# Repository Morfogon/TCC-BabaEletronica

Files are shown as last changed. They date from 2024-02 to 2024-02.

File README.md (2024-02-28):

# Baba Eletrônica Para Pais Deficientes Auditivos ( BabyCare )
Trabalho de conclusão de curso de Engenharia da Computação, Instituto Mauá de Tecnologia



O projeto consiste em:
- [x] Criação de modelos de aprendizagem para classificação e detecção de choro @NULLBYTE-RGH
- [x] Fazer captura de Som e Imagem do bebê com uma Webcam (Streaming) @NULLBYTE-RGH
- [x] Criar um Barramento de eventos para gerenciar a comunicação entre o serviço de classificação e periféricos @NULLBYTE-RGH
- [x] Criar meios de Autenticação e implementar criptografia @NULLBYTE-RGH
- [x] Fazer comunicação entre bracele e Baba eletrônica @NULLBYTE-RGH
- [x] Criar metodo de configuração da Baba a rede WIFI via bluetooth @NULLBYTE-RGH
- [x] Criação e implementação de um bracelete de uso do bebê para captura de movimentos e comunicação com a central (Intel NUC) @NULLBYTE-RGH
- [x] Criação e implementação de Modulo de controle de iluminação @NULLBYTE-RGH
- [x] Implementar serviços de forma eficiente, visando baixo uso de recursos @NULLBYTE-RGH
- [x] Criação e integração de um relógio inteligente que ligado ao celular via bluetooth recebe notificações e alerta os pais por meio de vibração e ou alerta visual @NULLBYTE-RGH
- [x] Criação de modelos de braceletes para impressao 3D para o pai e para o bebe @NULLBYTE-RGH
- [x] Criação de APP para comunicação com a baba eletrônica, possibilitando a visualização do bebê em tempo real bem como acesso a logs de choro @NULLBYTE-RGH @Morfogon

Status do projeto:



-----------------------------------------------------------------------------------------------------------------------------------------------

ConjuntoBABA

-----------------------------------------------------------------------------------------------------------------------------------------------

## ✔️ Técnicas, tecnologias e Recursos utilizados

- ``Python 3.10``
- ``Thony 3.3.13``
- ``Flask 2.2.3``
- ``Requests 2.28.2``
- ``Socket``
- ``Json``
- ``Numpy 1.23.5``
- ``Pyaudio 0.2.13``
- ``Time``
- ``Librosa 0.10.0.post2``
- ``Sklearn``
- ``Pickle``
- ``Datetime``
- ``Cv2 4.7.0.72``
- ``PIL``
- ``Io``
- ``Threading``
- ``Serial``
- ``RPi``
- ``Tensorflow 2.8.0``
- ``Soundfile 0.12.1``
- ``Machine``
- ``Imu``
- ``Math``
- ``matplotlib 3.7.1``
- ``os``
- ``Pydub 0.25.1``
- ``Scipy 1.10.1``
- ``Noisereduce``
- ``Comunicação UART``
- ``Comunicação I2C``
- ``Postman 10.13.0``
- ``Openssl``
- ``PyCharm Professional 231.8770.66, built on April 27, 2023`` ❤️
- ``DataSpell 231.8770.72, built on May 3, 2023`` ❤️

## 💻 Hardware para Treinamento e Desenvolvimento

- ``NVIDIA GeForce RTX 2060``
- ``Intel Core i7-8750H 2.20 GHz``
- ``16 GB RAM``

## Central da Baba
- ``Intel nuc dn2820fykh``
  
-----------------------------------------------------------------------------------------------------------------------------------------------
## Diagrama do projeto

Baba eletronicav3 drawio

VISAO COMPLETA BABA

## Modelos Testados:
#### Modelos clássicos, apresentaram uma boa precisão porém para a quantidade de dados disponíveis nos Datasets não foram eficientes
### SVC: 
SVC
### RandomForest:
Random
### DecisionTree:
Decision

-----------------------------------------------------------------------------------------------------------------------------------------------

#### Classificador MLP
#### 100 Neurônios para classificação de Choro, Silencio, Barulho e Risadas:
100Camadas
#### 600 Neurônios para classificação de Cólica, Arroto, Desconforto, Fome e cansaço:
600Camadas
#### 100 Neurônios com audios passados pelo microfone (Modelo mais recente):
output
#### A precisão máxima é atingida em vários momentos com diferentes features e com testes foi verificado que apesar de com 1 feature a precisão ser de 84%, com o uso de 26 Features, que também resulta em uma precisão de 84%, o modelo se sai melhor.
##### A classe CryingV2 utilizada no Neural.ipynb nada mais é do que uma pasta contendo ['belly_pain','discomfort','hungry','tired', 'Crying']
##### E o aprendizado foi feito em um ambiente utilizando Python versão 3.10
#### Sendo assim os modelos que serão utilizados em testes sem ruídos e estao disponiveis na pasta /Modelos são:
#### [x] modelo_Apenas_ChoroV4.pkl -> 95%
#### [x] modelo_Tipos_De_ChoroV4.pkl -> 84%
#### [x] Novo_Modelo_MLP_NormalizadoV3.pkl ->94.64%
##### É possível que o MLP tenha obtido melhores resultados porque ele é capaz de extrair mais informações relevantes dos dados de áudio e generalizar melhor para novos dados. Como mencionado anteriormente, os outros modelos podem ter limitações em termos de capacidade de lidar com dados mais complexos e não lineares.

##### Além disso, o fato de que o MLP teve um desempenho melhor no teste real pode ser uma indicação de que ele não sofreu tanto de overfitting quanto os outros modelos. O overfitting ocorre quando o modelo é ajustado demais aos dados de treinamento e não generaliza bem para novos dados. Se o MLP generalizou melhor para novos dados, é possível que ele tenha sofrido menos de overfitting do que os outros modelos.

-----------------------------------------------------------------------------------------------------------------------------------------------
 
### Problemas na captura de Áudio via Microfone:
#### Ao capturar o mesmo áudio que foi utilizado no treinamento via microfone foi observado uma diferença gritante:
### Espectrograma:
#### Louise é o audio original do dataset:
Espectrograma-Louise
#### Som do Bebe é o audio da Louise do dataset regravado a partir do microfone do computador:
Espectrograma Captura_WebCam

### Gráfico de Frequência:
#### Louise é o audio original do dataset:
Frequencia_Louise
#### Som do Bebe é o audio da Louise do dataset regravado a partir do microfone do computador:
Frequencia_WebCam

#### Foi testado o Treinamento do MLP com áudios gravados pelo Microfone, ao invés do uso do Dataset original, esses áudios do microfone nada mais são do que os áudios do dataset original, porém passados pelo Microfone que será usado para captura do áudio do Bebê, assim eliminando a interferência do Transdutor no reconhecimento.
#### Foi testado com 5 áudios de cada categoria e foi verificado que se obteve uma precisão de acerto de 4 em 5 dessa forma. Isso com 26 MFCCs e 100 Neurônios na camada. E apenas 20 dados para aprendizado sendo que dos 20, 20 % foram utilizados na validação resultando em 75 % de precisão. 
(Modelo: modelo_Tipos_De_ChoroVMicrofone.pkl)

### Áudios comparados (Original) e mesmo áudio, porém com influência do transdutor e com menor amplitude de dB:

#### Espectrogramas dessa vez com taxa de amostragem correta (Pois nos datasets baixados existem vários áudios fora do padrão 22k, isso foi corrigido junto ao tempo de áudio variado, agora limitados a 5 segundo e salvos em pastas com V2 no final do nome, dentro da pasta datasets) e com o microfone de um Galaxy s20+ ao invés do microfone da webcam:

Espectrograma Audio Original

Espectrograma Audio passado pelo Microfone

### Influência do dB na normalização do MFCC (Muito baixa a quase nula) assim comprovando que o volume não influencia na extração de fatures para criação do modelo/classificação:
##### Por camadas internas, entenda Neuronios, pois foi feito com apenas 1 camada, tirando a SoftMax
MFCC1

MFCC2

MFCC3

MFCC4

#### Novos datasets foram criados a partir dos datasets existentes, porém os áudios foram tocados em caixas de som que foram capturadas por uma webcam com microfone integrado, esses áudios então foram segmentados e salvos em suas respectivas classes, que foram utilizadas para treinamento do novo modelo e mais preciso de todos até o momento, com 95.38% de precisão, o modelo (modelo_Tipos_De_ChoroVMicrofone.pkl) faz uso de 90 mfcc's, 300 neurônios e 30% do dataset para validação. (dataset utilizado foi o Dataset_Microfone, onde todos os áudios limpos, em questão de samples e duração, foram tocados por uma caixa de som e capturados pelo microfone da webcam)

### O modelo mais recente:

#### O modelo atual 
[Novo_Modelo_MLP_NormalizadoV3.pkl](https://github.com/NULLBYTE-RGH/Baba-Eletronica-Para-Pais-Deficientes-Auditivos/blob/main/Modelos/Novo_Modelo_MLP_NormalizadoV3.pkl) junto ao 
[Scaler](https://github.com/NULLBYTE-RGH/Baba-Eletronica-Para-Pais-Deficientes-Auditivos/blob/main/Modelos/scalers_Novo_Modelo_MLP_NormalizadoV3.pkl)
faz uso de 1 camada interna com apenas 40 Neurônios e tem como entrada da rede 100 mfccs sendo o modelo mais leve e menos complexo ate o momento, atingindo uma precisao de 94.64%. Ele foi treinado com um novo dataset, que na verdade sao usados os mesmo audios que tinham no V2, porem eles foram tocados atraves de uma caixa de som nova e mais robusta, e alem disso foi feita uma limpeza manual em cada audio, removendo audios ruins ou inconsistentes com a classe. Junto a isso com a uma limpeza adicional nos audios, resultou em uma diminuição do Dataset, resultando em 76 audios de choro, 38 de risada e 72 de barulhos externos, visto um certo desbalanceamento foi tantado fazer ajustes ao modelo aplicando diferentes pesos as clases e fazendo dados sinteticos, e  resultado final foi :

Metricas Classificador

#### As especificações da nova caixa de som é : modelo: ep310, rms: 5w, resposta a frequencia: 200hz - 18 khz, sensibilidade de entrada: 350 mv, voltagem: 5v dc, conexão: p2

#### Os audios foram reproduzidos com o som maximo da caixa de som, porem com o nivel 80 % do windows, e a distancia entre a webcan e a caixa de som é de cerca de 1 metro
-----------------------------------------------------------------------------------------------------------------------------------------------

## Bracelete do Bebê
#### Componentes:
##### [X] RP2040
##### [X] HC05
##### [X] GY-521

Schematic_Braceletes_2023-05-07

[Schematic_Braceletes_2023-05-07.pdf](https://github.com/NULLBYTE-RGH/Baba-Eletronica-Para-Pais-Deficientes-Auditivos/files/11414012/Schematic_Braceletes_2023-05-07.pdf)





-----------------------------------------------------------------------------------------------------------------------------------------------

## Bracelete dos Pais
#### Componentes:
##### [X] RP2040
##### [X] HC05
##### [X] Motor Vibrador 3v

Schematic_Bracelete PAI_2023-05-12

-----------------------------------------------------------------------------------------------------------------------------------------------
## Modulo de Iluminação

Schematic_Luz_2023-09-06

-----------------------------------------------------------------------------------------------------------------------------------------------

## 🔨 Funcionalidades: [Barramento de eventos](https://github.com/NULLBYTE-RGH/Baba-Eletronica-Para-Pais-Deficientes-Auditivos/tree/main/Barramento%20de%20eventos)
#### Ao [iniciar](https://github.com/NULLBYTE-RGH/Baba-Eletronica-Para-Pais-Deficientes-Auditivos/blob/main/Fluxograma/Inicializa%C3%A7%C3%A3o.pdf) o dispositivo o [serviço de inicialização](https://github.com/NULLBYTE-RGH/Baba-Eletronica-Para-Pais-Deficientes-Auditivos/blob/main/Barramento%20de%20eventos/servi%C3%A7os/Servico_de_Inicializacao.py) entra em execução, se for a primeira inicialização, o usuario deverá, parear seu celular com a Raspberry pi 3 e segurar o botão nela contido por X segundos, sendo assim o serviço: [Serviço_de_conexao_wifi](https://github.com/NULLBYTE-RGH/Baba-Eletronica-Para-Pais-Deficientes-Auditivos/blob/main/Barramento%20de%20eventos/servi%C3%A7os/Servico_Rede_WIFI.py) entrara em funcionamento, a partir desse momento o usuário por meio do app deverá informar o SSID(nome) da rede [wifi](https://github.com/NULLBYTE-RGH/Baba-Eletronica-Para-Pais-Deficientes-Auditivos/blob/main/Fluxograma/Rede%20WIFI.pdf) e sua senha, quando conectado corretamente, é retornado o IP da Baba eletronica na rede local e é solicitado a criação de pelo menos um usuario e uma senha, tendo a opção da criação de multiplas contas. Ao finalizar, o serviço [Barramento](https://github.com/NULLBYTE-RGH/Baba-Eletronica-Para-Pais-Deficientes-Auditivos/blob/main/Barramento%20de%20eventos/Barramento.py) entrara em execução, juntamente aos serviços : [Bracelete](https://github.com/NULLBYTE-RGH/Baba-Eletronica-Para-Pais-Deficientes-Auditivos/blob/main/Barramento%20de%20eventos/Bracelete.py), [Camera](https://github.com/NULLBYTE-RGH/Baba-Eletronica-Para-Pais-Deficientes-Auditivos/blob/main/Barramento%20de%20eventos/Camera.py), [Microfone](https://github.com/NULLBYTE-RGH/Baba-Eletronica-Para-Pais-Deficientes-Auditivos/blob/main/Barramento%20de%20eventos/Microfone.py) e [iluminacao](https://github.com/NULLBYTE-RGH/Baba-Eletronica-Para-Pais-Deficientes-Auditivos/blob/main/Barramento%20de%20eventos/iluminacao.py)
##### Exemplo de saida quando a Baba esta sendo configurada pelo [Serviço_de_conexao_wifi](https://github.com/NULLBYTE-RGH/Baba-Eletronica-Para-Pais-Deficientes-Auditivos/blob/main/Barramento%20de%20eventos/servi%C3%A7os/Servi%C3%A7o_de_conexao_wifi.py), essa saida foi gerada com uso do app [Serial Bluetooth Terminal](https://play.google.com/store/apps/details?id=de.kai_morich.serial_bluetooth_terminal&pli=1) para Android, fazendo as requisições que serao feitas pelo APP:
Screenshot_20230508_000623_Serial Bluetooth Terminal
-----------------------------------------------------------------------------------------------------------------------------------------------
## [Rotas](https://github.com/NULLBYTE-RGH/Baba-Eletronica-Para-Pais-Deficientes-Auditivos/blob/main/Fluxograma/Barramento.pdf)

##### O Barramento em si [Barramento.py](https://github.com/NULLBYTE-RGH/Baba-Eletronica-Para-Pais-Deficientes-Auditivos/blob/main/Barramento%20de%20eventos/Barramento.py) tem diversas rotas e roda na porta padrão 5000 (Atualmente tudo funciona por meio de HTTP, futuramente sera implementado HTTPS, para uma maior segurança da baba como um todo):
###### Para todas as requisições (Exceto /camera), deve ser fornecido tanto o usuario como a senha : (usuario&senha) em formato JSON no corpo da requisição como : 
##### {
##### "usuario":"user1",
##### "senha":"pass1"
##### }
##### ``Caso tenha um metodo associado a rota (?tipo=X)``
##### Para criar o certificado e par de chaves para usar HTTPS TLS use o OpenSSL: 
##### ``openssl req -x509 -newkey rsa:4096 -nodes -out cert.pem -keyout key.pem -days 365`` 
##### Este comando criará um certificado autoassinado com uma chave RSA de 4096 bits e uma validade de 365 dias
###### As requisições podem ser consultadas [aqui](https://github.com/NULLBYTE-RGH/Baba-Eletronica-Para-Pais-Deficientes-Auditivos/blob/main/Requisi%C3%A7%C3%B5es/Barramento.postman_collection.json)
-----------------------------------------------------------------------------------------------------------------------------------------------
### '[/](https://github.com/NULLBYTE-RGH/Baba-Eletronica-Para-Pais-Deficientes-Auditivos/blob/main/Fluxograma/Barramento.pdf)'
###### Deve ser acessada via método POST, essa rota serve para escrever o celular como Observer dos eventos do bebê, para evitar excessivo tráfego na rede. Ao momento que o celular sabe o endereço da baba na rede, ele envia essa requisição ao celular e o barramento se encarrega de avisar o celular caso tenha ocorrido alguma mudança na movimentação do bebê ou caso tenha ocorrido choro. assim o [celular](https://github.com/NULLBYTE-RGH/Baba-Eletronica-Para-Pais-Deficientes-Auditivos/blob/main/Barramento%20de%20eventos/Simular_Celular.py) como simulado, pode tomar a decisão de alertar o usuário. Mais detalhadamente, essa rota ao receber a requisição extrai o IP do celular na rede, bem como a porta em que o celular escolheu para ouvir notificações, essa porta é enviada pelo celular no corpo da requisição, essa porta é de escolha do celular, podendo ser modificada caso necessário, em tempo de Execução.


-----------------------------------------------------------------------------------------------------------------------------------------------
### '/evento'
###### É uma rota de método POST na qual ``o usuário não deve acessar`` (para isso é feita uma checagem de IP na hora que o barramento recebe a requisição, assegurando que o IP do cliente é da rede de loopback, assim só permitindo que serviços locais, iniciem requisiçoes a essa rota), essa rota é de acesso dos serviços em execução, ao ocorrer alguma mudança de estado dos servicos execução,o serviço alerta o barramento por meio desta rota, a qual se encarrega de notificar o celular, que se inscreveu como Observer na rota '/'. Mais detalhadamente: os serviços bracelete e microfone que fazem acesso a essa rota, fazendo uma requisição do tipo: 'http://127.0.0.1:5000/evento?tipo=1' o argumento (?tipo=X) é o que determina de onde o alerta surgiu, sendo tipo = 1 Evento de Movimentação, tipo = 2 Evento do Microfone.
-----------------------------------------------------------------------------------------------------------------------------------------------
### '/[camera](https://github.com/NULLBYTE-RGH/Baba-Eletronica-Para-Pais-Deficientes-Auditivos/blob/main/Fluxograma/Camera.pdf)'
###### Essa rota faz uso do método GET e caso a requisição seja feita com o argumento tipo (?tipo=1) o retorno é uma imagem tirada pela webcam do bebê, caso seja diferente de (?tipo=1) como (?tipo=2 etc) o barramento entende a requisição como sendo de streaming de vídeo.
Requisição
-----------------------------------------------------------------------------------------------------------------------------------------------
### '/[microfone](https://github.com/NULLBYTE-RGH/Baba-Eletronica-Para-Pais-Deficientes-Auditivos/blob/main/Fluxograma/Microfone.pdf)'
###### Faz uso do método POST e possui 2 métodos de acesso, (?tipo=1) retorna o que o modelo está detectando no momento da requisição, como (choro, silencio, barulho ou risada), podendo ter um retorno vazio caso o modelo não esteja detectando nada no momento e o método de acesso (?tipo=2) que retorna o LOG de todas as detecções já realizada até o momento, contendo o que foi detectado, hora e minuto, bem como data, tudo em formato JSON.
RequisiçãoMicrofone
-----------------------------------------------------------------------------------------------------------------------------------------------
### '/[iluminacao](https://github.com/NULLBYTE-RGH/Baba-Eletronica-Para-Pais-Deficientes-Auditivos/blob/main/Fluxograma/Ilumina%C3%A7%C3%A3o.pdf)'
###### Usa o método POST e possui 3 tipos de operações: (?tipo=1) liga a luz do quarto do bebê, (?tipo=2) desliga a luz do quarto do bebê e (?tipo=3) retorna o status da luz do quarto do bebê, sendo acesa ou apagada.
-----------------------------------------------------------------------------------------------------------------------------------------------
### '/[bracelete](https://github.com/NULLBYTE-RGH/Baba-Eletronica-Para-Pais-Deficientes-Auditivos/blob/main/Fluxograma/Servi%C3%A7o%20Bracelete.pdf)'
###### Faz uso do método POST e possui 2 modos de operação: (?tipo=1) retorna o status do bebê, como se movimentando ou não, hora, dia, minuto e temperatura do quarto. Caso não ele é um valor JSON vazio e (?tipo=2) retorna os LOGS de movimentações do bebê.
-----------------------------------------------------------------------------------------------------------------------------------------------

## APP:

APPtela1
APPtela2
APPtela3
BraceleteBABA

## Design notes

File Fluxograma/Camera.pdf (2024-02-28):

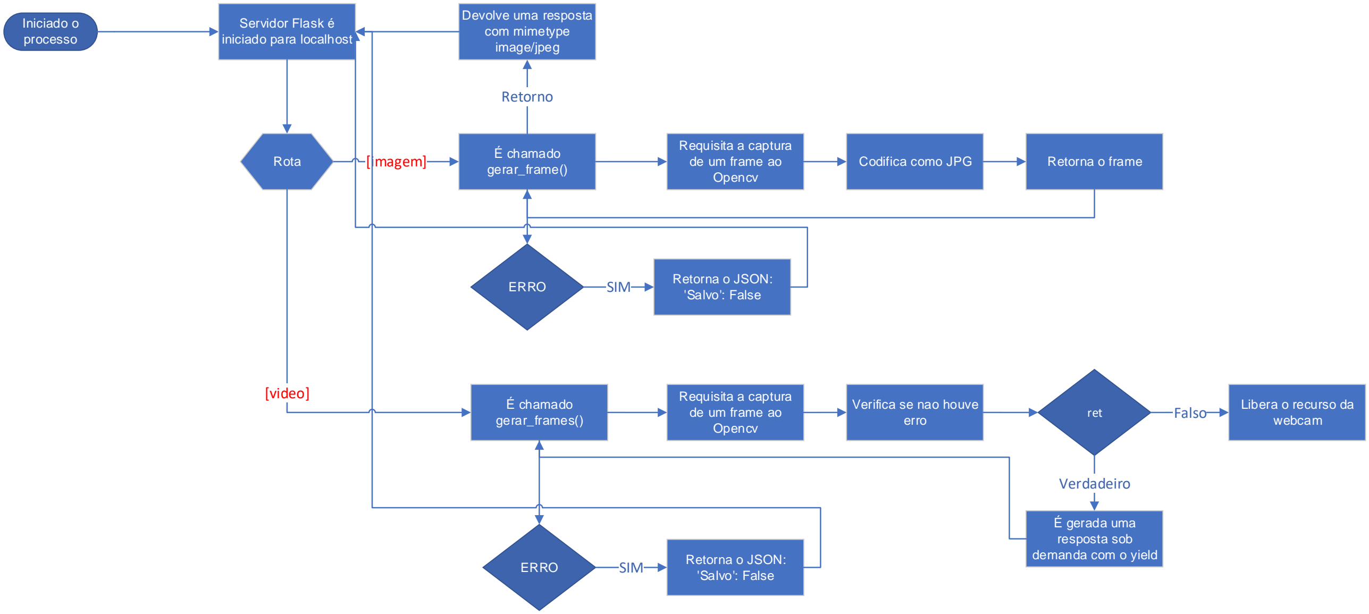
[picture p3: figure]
Iniciado o processo; Servidor Flask é iniciado para localhost; Rota; É chamado; gerar_frame() [imagem]; Requisita a captura de um frame ao Opencv; Codifica como JPG; Retorna o frame; Devolve uma resposta com mimetype image/jpeg; Retorno; ERRO; Retorna o JSON:; 'Salvo': False SIM; gerar_frames(); [video]; Requisita a captura; de um frame ao Opencv; É gerada uma; resposta sob demanda com o yield; Verifica se nao houve erro; ret; Libera o recurso da webcam Falso; Verdadeiro

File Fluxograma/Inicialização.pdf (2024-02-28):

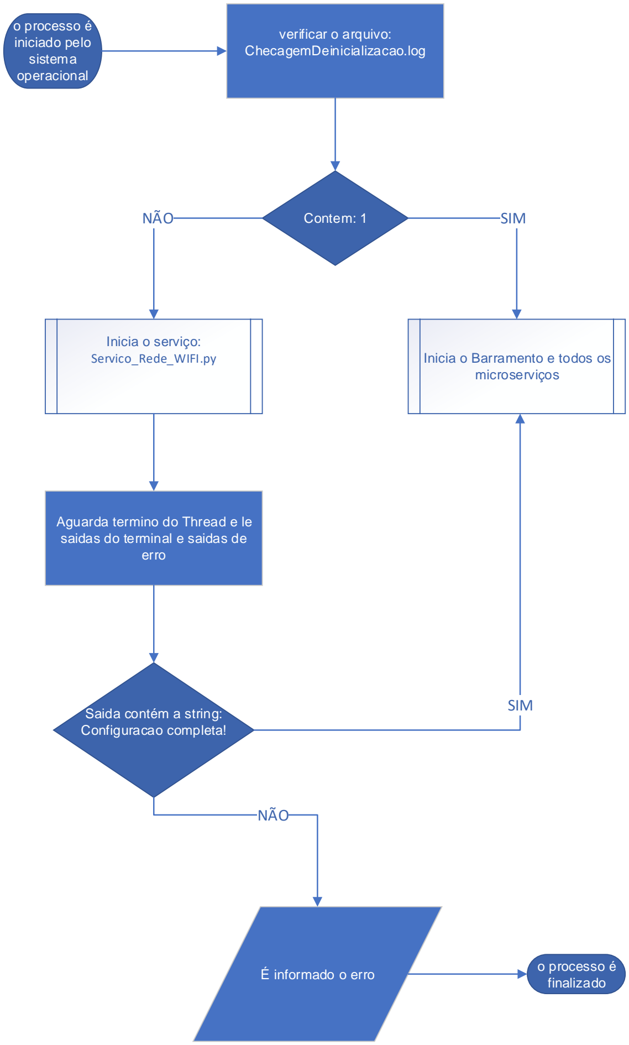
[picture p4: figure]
verificar o arquivo: ChecagemDeinicializacao.log; NÃO; Contem: 1; SIM; Inicia o serviço:; microserviços; Aguarda termino do Thread e le saidas do terminal e saidas de erro; Saida contém a string: Configuracao completa!; É informado o erro; o processo é finalizado; o processo é iniciado pelo sistema operacional

Servico_Rede_WIFI.py | Inicia o Barramento e todos os

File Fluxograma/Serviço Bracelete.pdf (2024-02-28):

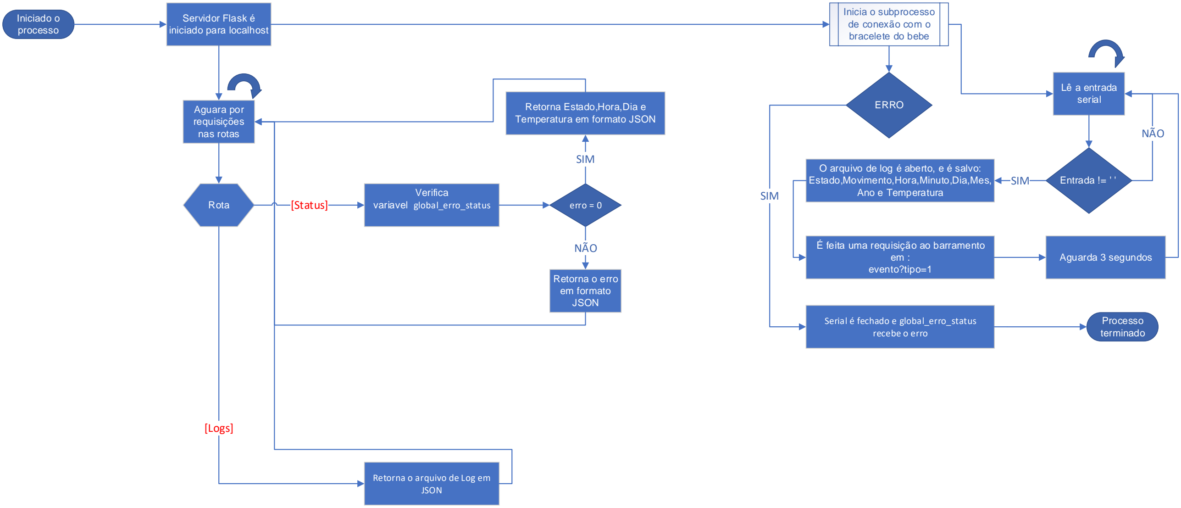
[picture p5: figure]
Iniciado o processo; Servidor Flask é iniciado para localhost; Aguara por requisições nas rotas; Rota; Verifica; [Status]; variavel global_erro_status; erro = 0; Retorna o erro em formato JSON; NÃO; Retorna Estado,Hora,Dia e Temperatura em formato JSON; SIM; Retorna o arquivo de Log em JSON; [Logs]; Inicia o subprocesso de conexão com o bracelete do bebe; Lê a entrada serial; Entrada != ' '; O arquivo de log é aberto, e é salvo: Estado,Movimento,Hora,Minuto,Dia,Mes, Ano e Temperatura; É feita uma requisição ao barramento; em : evento?tipo=1; Aguarda 3 segundos; ERRO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

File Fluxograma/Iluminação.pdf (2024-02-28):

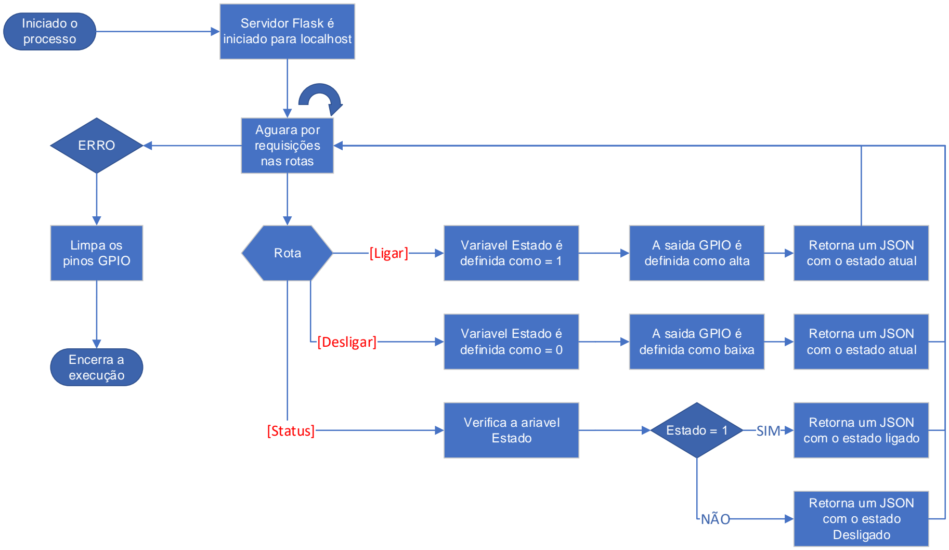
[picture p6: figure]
Iniciado o processo; Servidor Flask é iniciado para localhost; Aguara por requisições nas rotas; Rota; Variavel Estado é; definida como = 1 [Ligar]; A saida GPIO é; definida como alta; Retorna um JSON com o estado atual; Variavel Estado é definida como = 0; A saida GPIO é definida como baixa; Retorna um JSON com o estado atual [Desligar]; Verifica a ariavel; Estado [Status]; Estado = 1; Retorna um JSON; com o estado ligado SIM; Retorna um JSON com o estado Desligado; NÃO; ERRO; Limpa os pinos GPIO; Encerra a execução

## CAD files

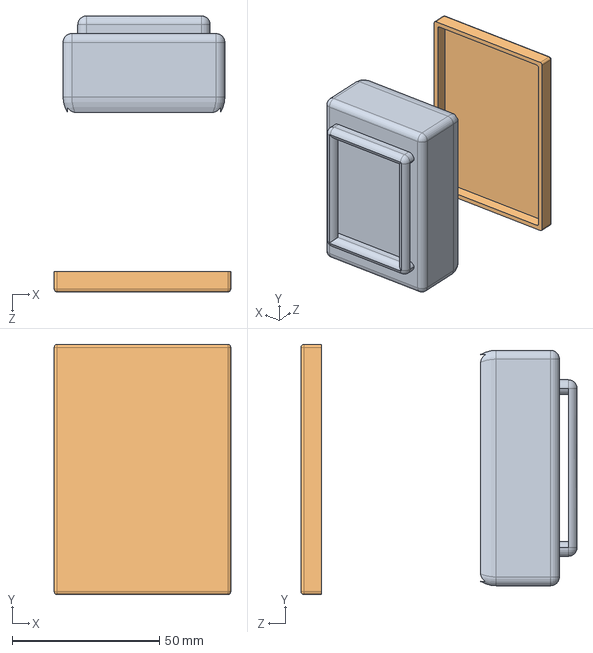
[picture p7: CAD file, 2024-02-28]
Modelos_3D/Mont_Bracelete_Pai.SLDASM
60.0 x 85.0 x 93.8 mm
Bracelete_Pai
Tampa_Bracelete_Pai

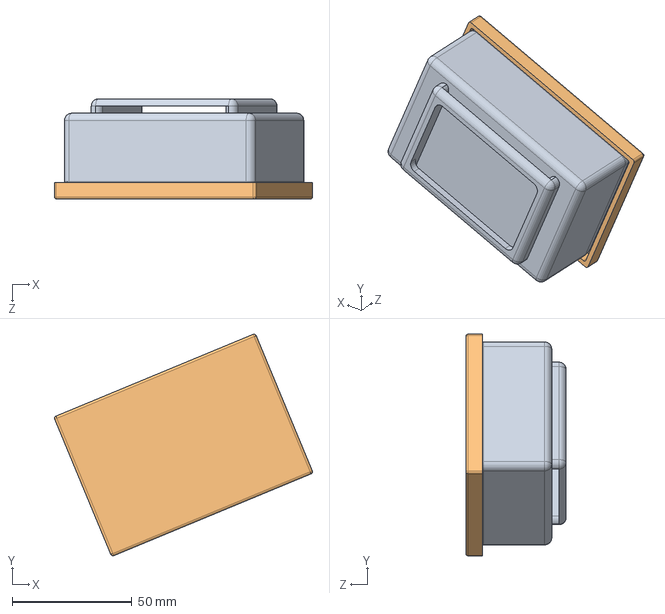
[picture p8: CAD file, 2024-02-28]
Modelos_3D/Mont_Bracelete_Filho.SLDASM
107.6 x 92.4 x 41.9 mm
Bracelete_Bebe
Tampa_Bracelete_Filho

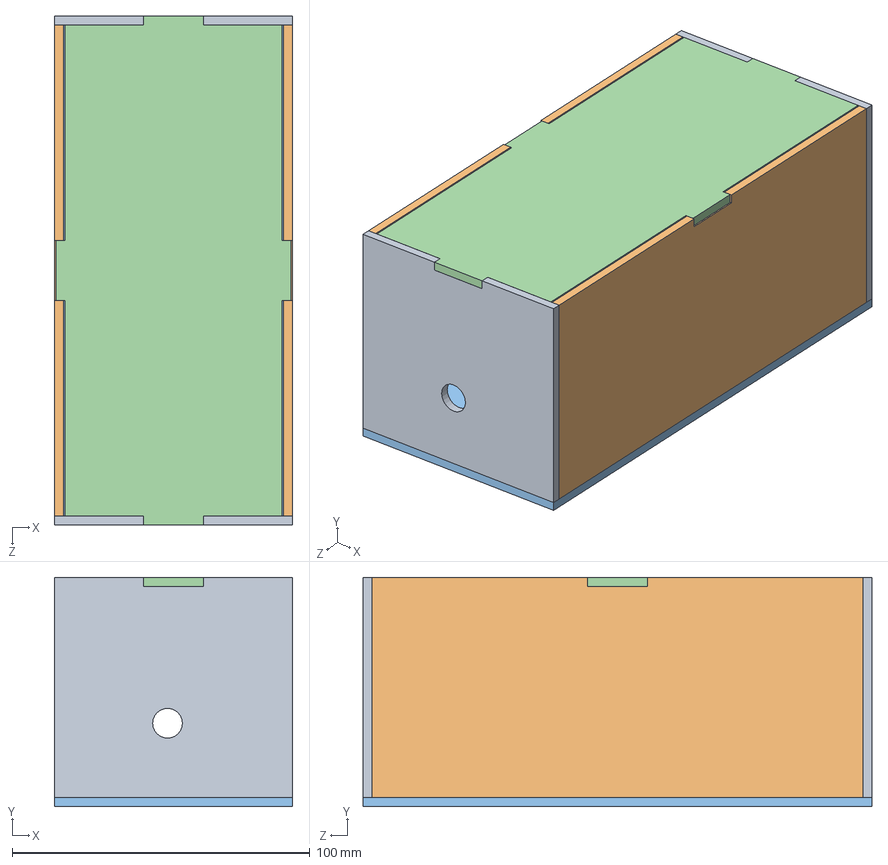
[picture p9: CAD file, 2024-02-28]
Modelos_3D/Mont1.SLDASM
80.0 x 77.0 x 171.0 mm
Fundo-Novo-caixa-luz x 2
Lateral-caixa-luz-nova x 2
Base-Nova-caixa-luz
Tampa-Caixa-Luz

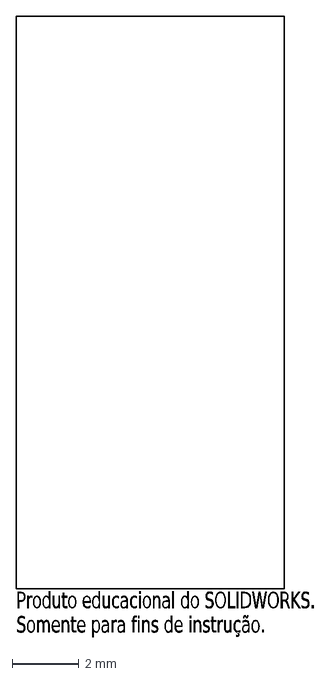
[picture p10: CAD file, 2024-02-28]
Modelos_3D/JoaoVitor_Base-Nova-caixa-luz_laser_1.DXF
Produto educacional do SOLIDWORKS.
Somente para fins de instrução.

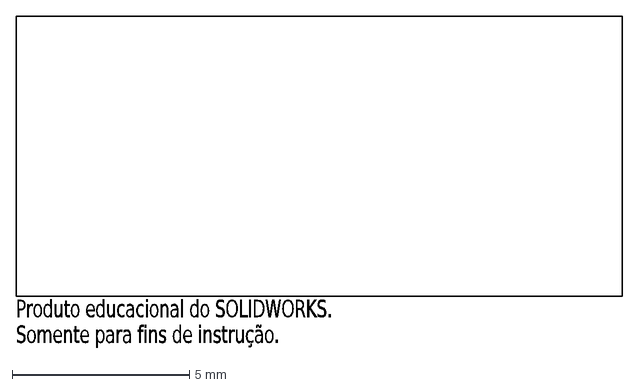
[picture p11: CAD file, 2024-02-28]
Modelos_3D/JoaoVitor_Caixa-Luz-Base_laser_1.DXF
Produto educacional do SOLIDWORKS.
Somente para fins de instrução.

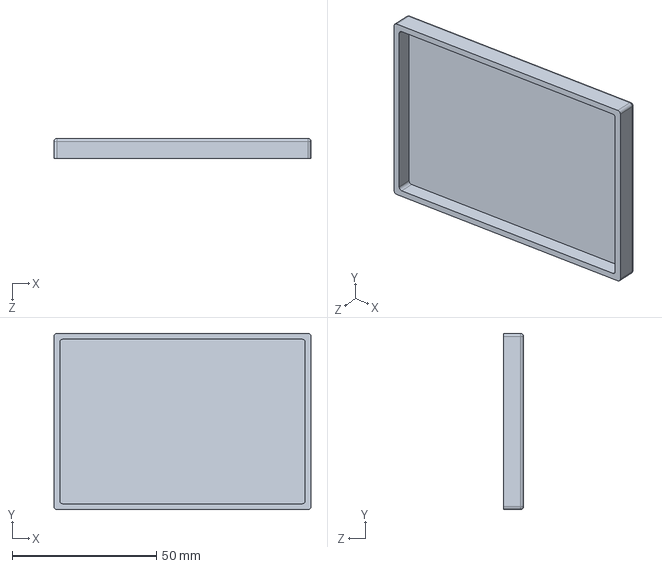
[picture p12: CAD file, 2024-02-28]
Modelos_3D/Tampa_Bracelete_Pai.SLDPRT
89.0 x 61.0 x 7.00 mm

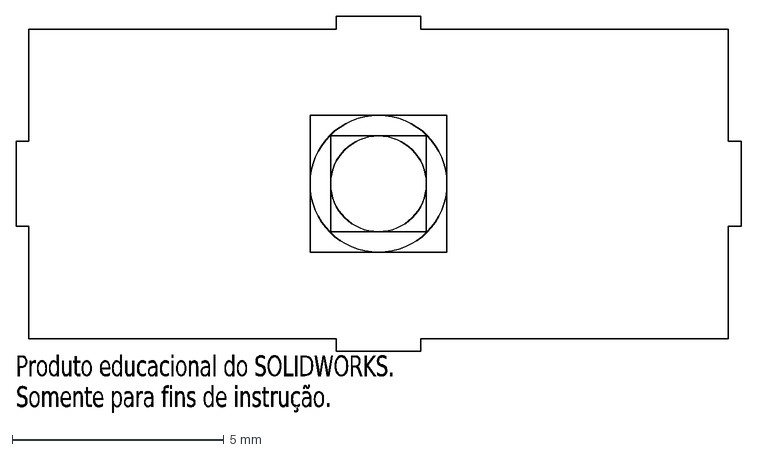
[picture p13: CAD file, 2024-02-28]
Modelos_3D/JoaoVitor_Caixa-Luz-TampaGravacaoLogo_laser_1.DXF
Produto educacional do SOLIDWORKS.
Somente para fins de instrução.

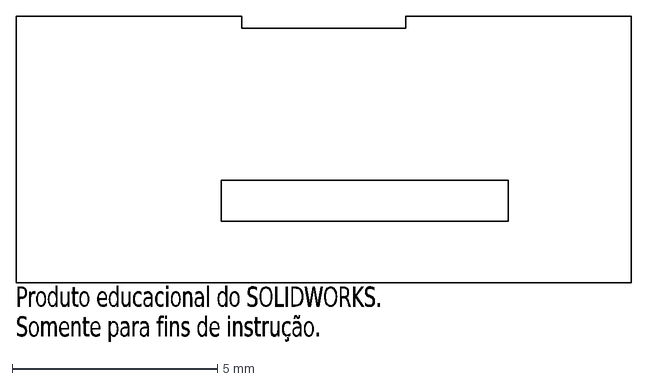
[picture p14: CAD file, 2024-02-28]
Modelos_3D/JoaoVitor_Caixa-baba-Lateral2_laser_1.DXF
Produto educacional do SOLIDWORKS.
Somente para fins de instrução.

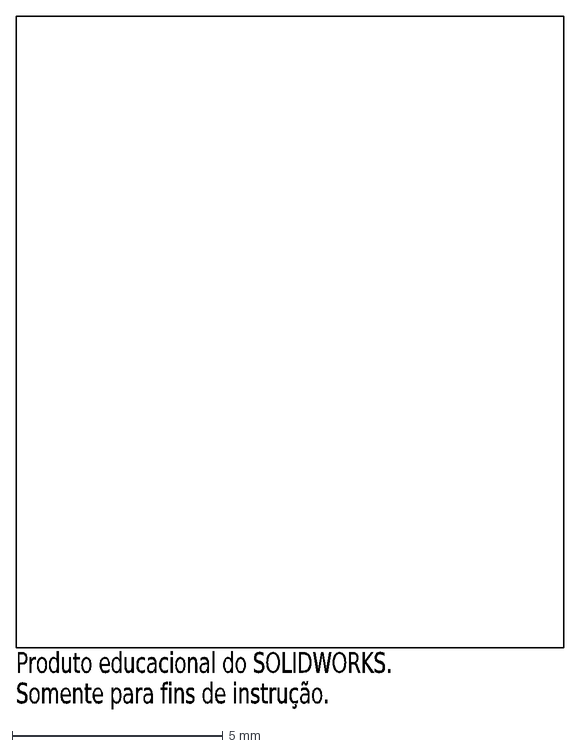
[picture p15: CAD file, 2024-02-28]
Modelos_3D/JoaoVitor_Caixa-baba-Base_laser_1.DXF
Produto educacional do SOLIDWORKS.
Somente para fins de instrução.

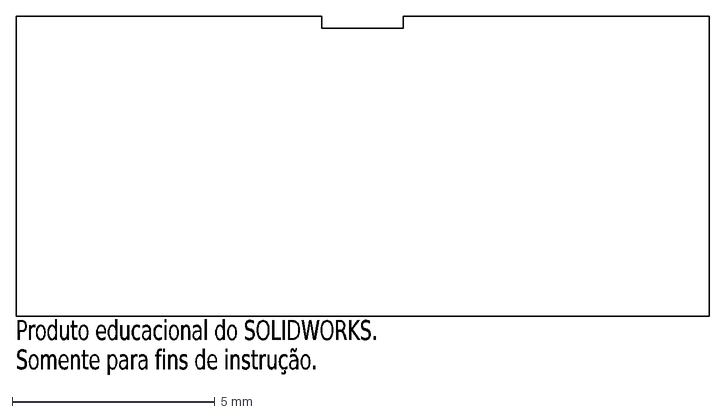
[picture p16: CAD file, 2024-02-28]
Modelos_3D/JoaoVitor_Caixa-Luz-Lateral2_laser_1.DXF
Produto educacional do SOLIDWORKS.
Somente para fins de instrução.

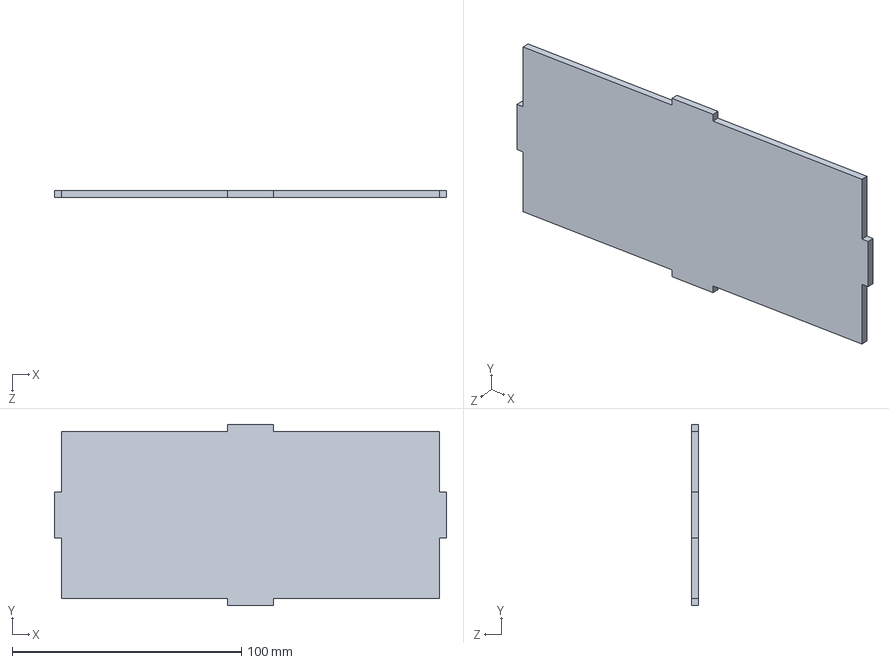
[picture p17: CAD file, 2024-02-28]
Modelos_3D/Tampa-Caixa-Luz.SLDPRT
171.0 x 79.0 x 3.00 mm

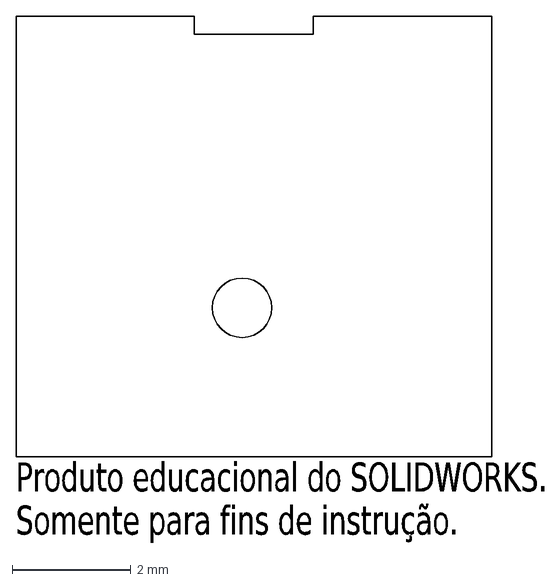
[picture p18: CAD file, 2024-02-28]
Modelos_3D/JoaoVitor_Caixa-Luz-FundoNovo_laser_2.DXF
Produto educacional do SOLIDWORKS.
Somente para fins de instrução.

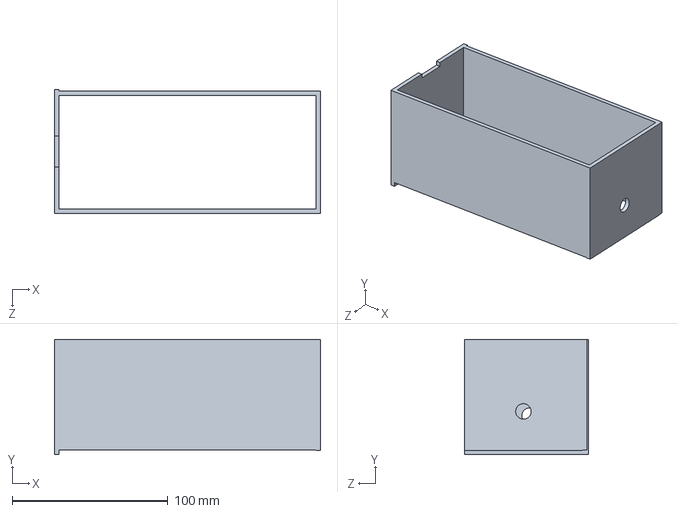
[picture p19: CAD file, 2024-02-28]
Modelos_3D/Caixa-Luz.SLDPRT
171.0 x 74.0 x 80.0 mm

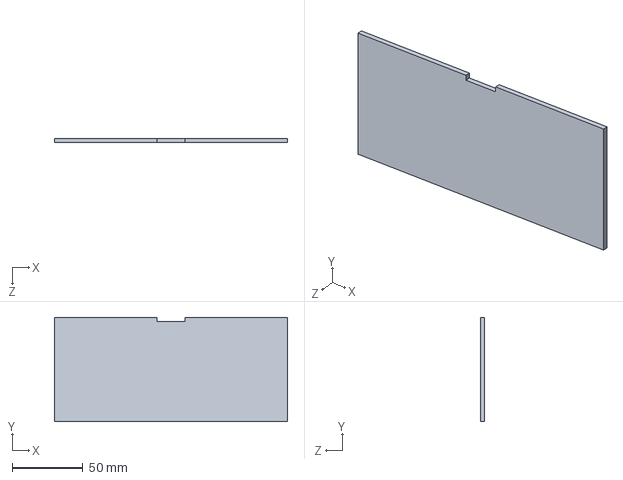
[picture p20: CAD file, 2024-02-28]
Modelos_3D/Lateral-caixa-luz-nova.SLDPRT
165.0 x 74.0 x 3.00 mm

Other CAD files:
Modelos_3D/JoaoVitor_TampaBraceletePai_3D_1.STL
Modelos_3D/Novo-Fundo-Caixa-baba.SLDPRT
Modelos_3D/Caixa-baba-Tampa.SLDPRT
Modelos_3D/JoaoVitor_Caixa-baba-TampaGravacaoLogo_laser_1.DXF
Modelos_3D/Base-Nova-caixa-luz.SLDPRT
Modelos_3D/Bracelete_Bebe.SLDPRT
Modelos_3D/Bracelete_Pai.SLDPRT
Modelos_3D/Caixa-baba.SLDPRT
Modelos_3D/Fundo-Novo-caixa-luz.SLDPRT
Modelos_3D/JoaoVitor_BraceleteBebe_3D_1.STL
Modelos_3D/JoaoVitor_BraceletePai_3D_1.STL
Modelos_3D/JoaoVitor_Caixa-Luz-Frente_laser_1.DXF
Modelos_3D/JoaoVitor_Caixa-Luz-Fundo_laser_1.DXF
Modelos_3D/JoaoVitor_Caixa-Luz-Lateral1Nova_laser_1.DXF
Modelos_3D/JoaoVitor_Caixa-Luz-Lateral1_laser_1.DXF
Modelos_3D/JoaoVitor_Caixa-Luz-Lateral2Nova_laser_1.DXF
Modelos_3D/JoaoVitor_Caixa-baba-Frente_laser_1.DXF
Modelos_3D/JoaoVitor_Caixa-baba-Fundo_laser_1.DXF
Modelos_3D/JoaoVitor_Caixa-baba-Lateral1NOVA_laser_1.DXF
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

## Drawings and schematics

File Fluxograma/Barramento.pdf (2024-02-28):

[\]

## NÃO

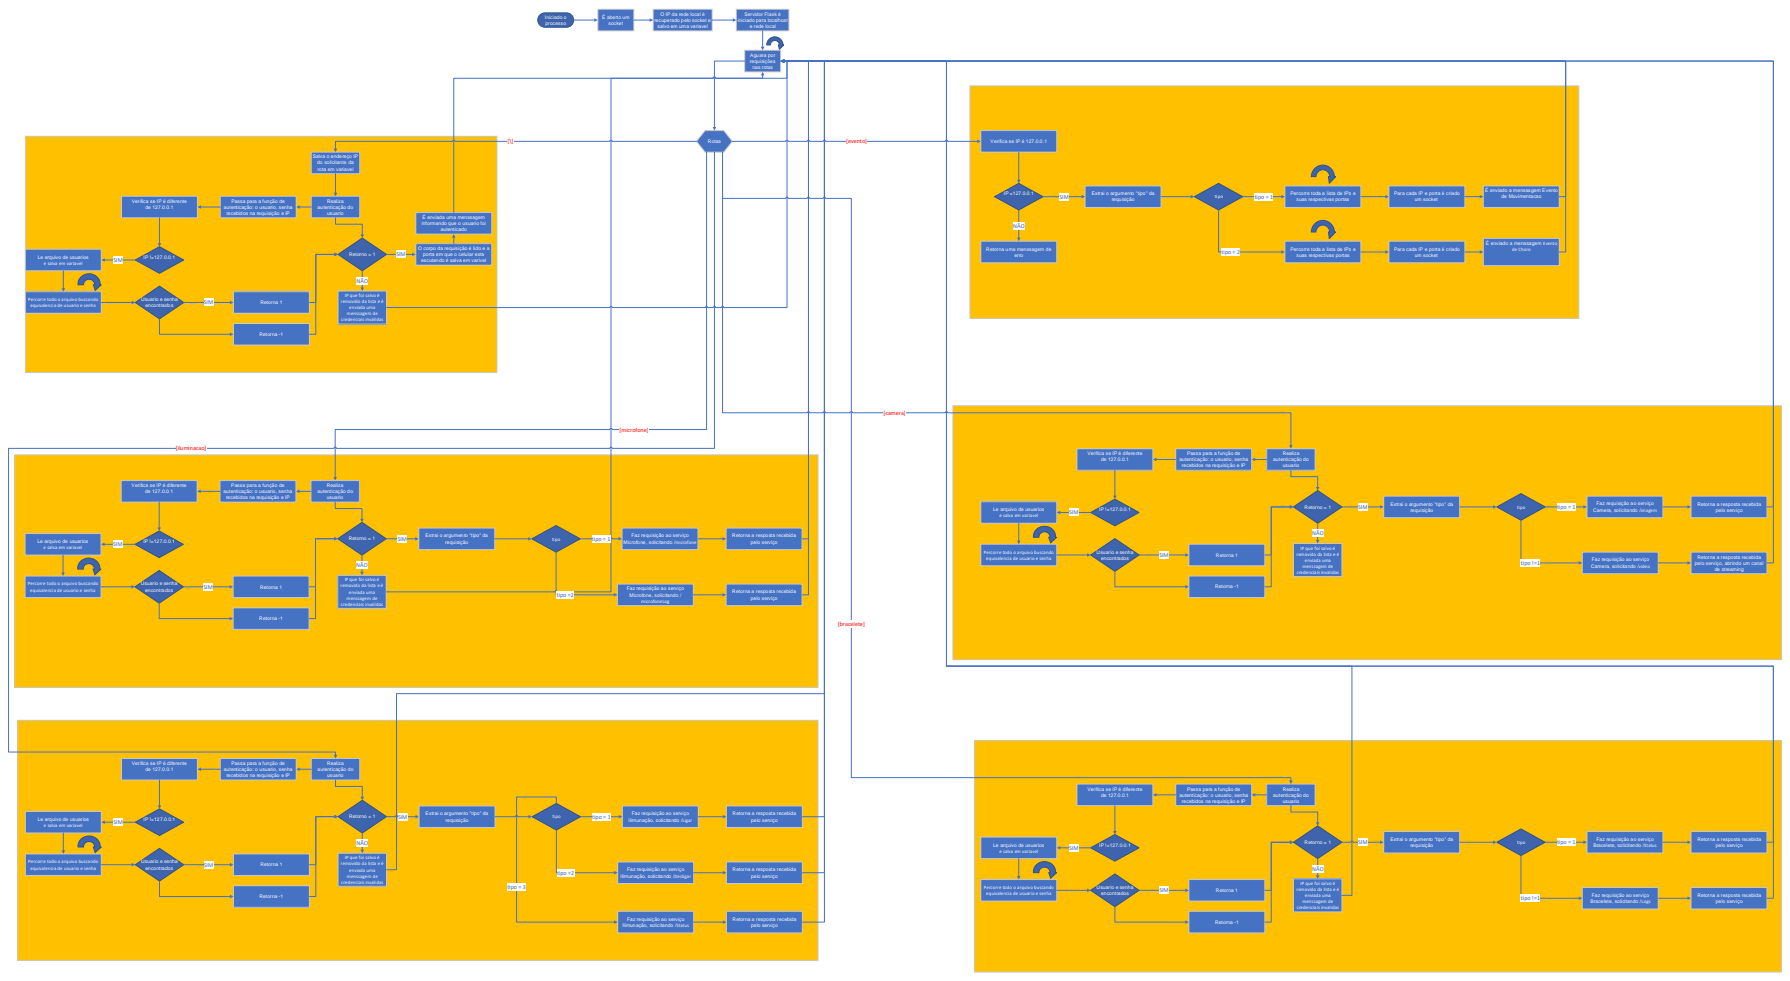
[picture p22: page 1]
Iniciado o processo; É aberto um; socket; Aguara por requisições nas rotas; Rotas; Realiza autenticação do usuario; Le arquivo de usuarios; e salva em variavel; SIM; Usuario e senha; encontrados; Retorna 1; Retorna -1; Retorno = 1; autenticado; [evento]; Verifica se IP é 127.0.0.1; erro; NÃO; requisição; tipo; tipo = 1; um socket; de Movimentacao; de Choro; tipo = 2; [camera]; Usuario e senha encontrados; pelo serviço; de streaming; tipo !=1; [microfone]; Extrai o argumento "tipo" da; tipo =2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

O IP da rede local é
recuperado pelo socket e
salvo em uma variavel

Servidor Flask é
iniciado para localhost
e rede local

Salva o endereço IP
do solicitante da
rota em variavel

É enviado a menssagem Evento

Extrai o argumento "tipo" da

Percorre toda a lista de IPs e
suas respectivas portas

Para cada IP e porta é criado

Verifica se IP é diferente

Passa para a função de
autenticação: o usuario, senha
recebidos na requisição e IP

É enviada uma menssagem
informando que o usuario foi

O corpo da requisição é lido e a
porta em que o celular esta
escutando é salva em varivel

Retorna uma menssagem de

IP que foi salvo é
removido da lista e é
enviada uma
menssagem de
credenciais invalidas

Percorre todo o arquivo buscando
equivalencia de usuario e senha

Faz requisição ao serviço
Camera, solicitando /imagem

Retorna a resposta recebida

e salva em variavel

Microfone, solicitando /microfone

pelo serviço, abrindo um canal

Camera, solicitando /video

Microfone, solicitando /
microfoneLog

Ilimunação, solicitando /Ligar

Bracelete, solicitando /Status

Ilimunação, solicitando /Desligar

Bracelete, solicitando /Logs

Ilimunação, solicitando /Status

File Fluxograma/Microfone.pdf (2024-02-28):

## SIM

## [microfone]

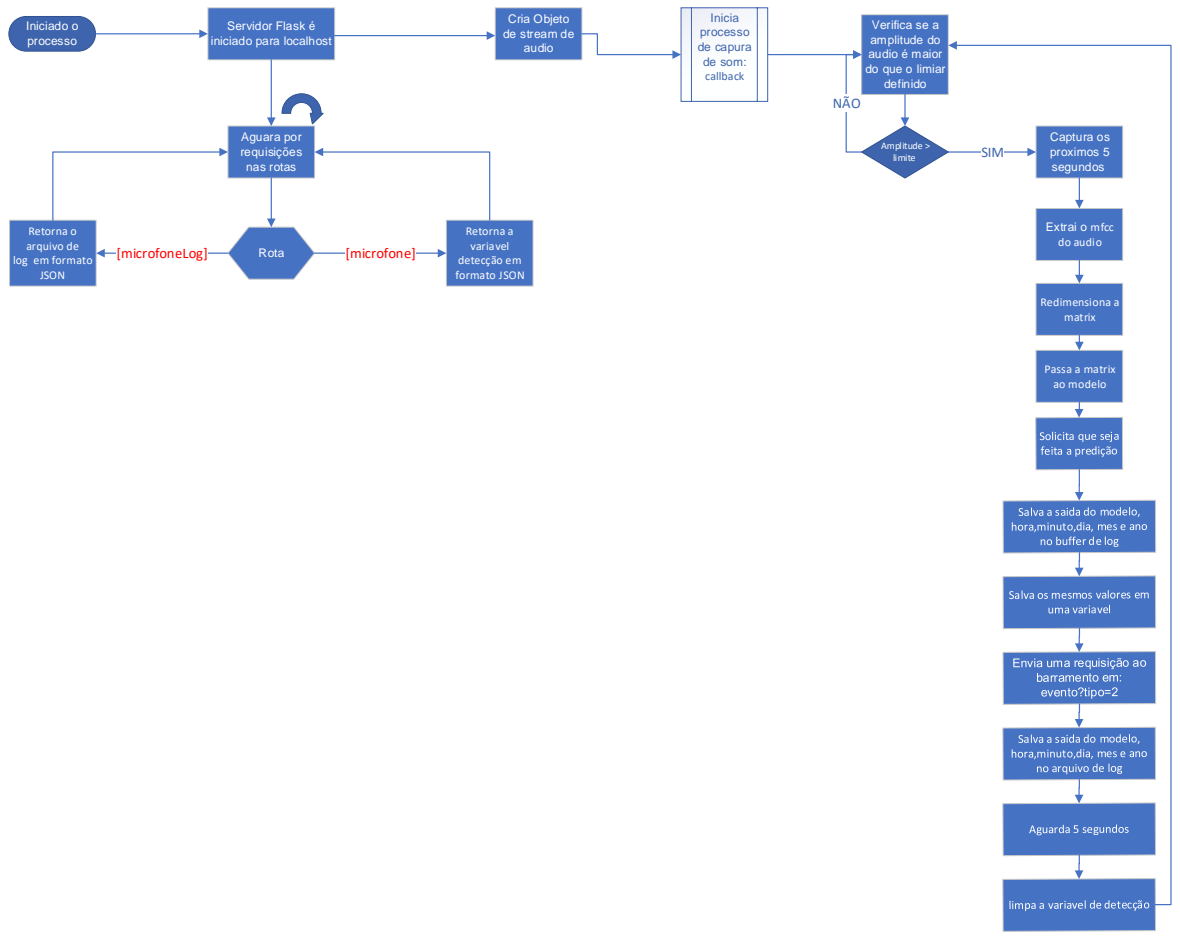
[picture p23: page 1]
Iniciado o processo; Aguara por requisições nas rotas; Rota; Inicia processo de capura de som: callback; Amplitude > limite; Captura os proximos 5 segundos; Extrai o mfcc do audio; Redimensiona a matrix; Passa a matrix ao modelo; Retorna a variavel detecção em formato JSON; [microfoneLog]; NÃO

Cria Objeto
de stream de
audio

Servidor Flask é
iniciado para localhost

Verifica se a
amplitude do
audio é maior
do que o limiar
definido

Retorna o
arquivo de
log em formato
JSON

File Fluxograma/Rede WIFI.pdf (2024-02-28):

## NÃO

## SIM

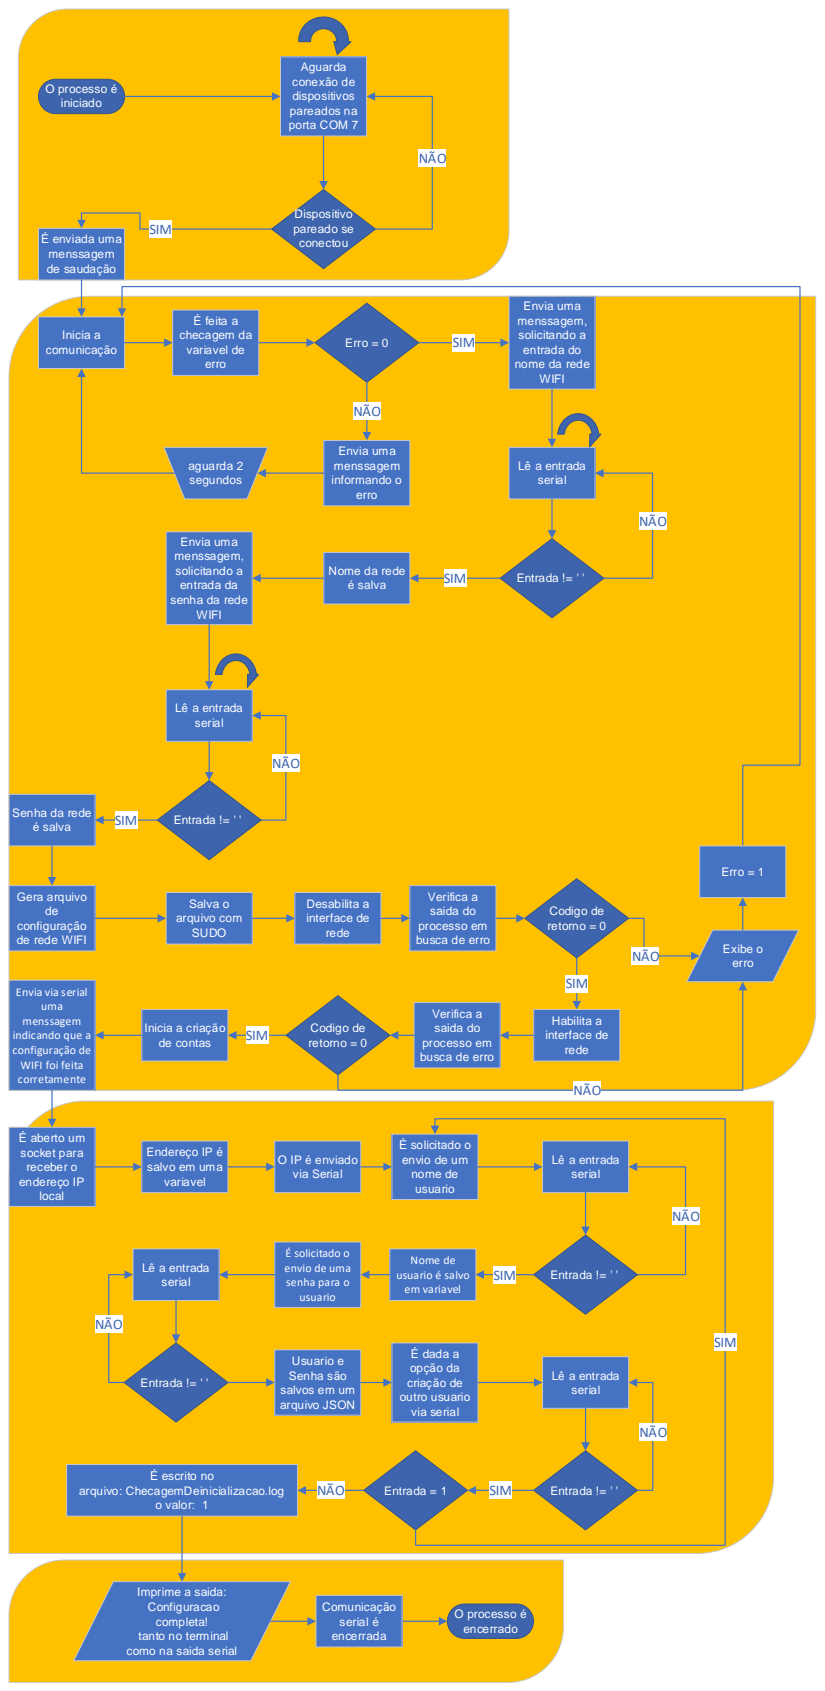
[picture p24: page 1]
Aguarda conexão de dispositivos pareados na porta COM 7; O processo é iniciado; Dispositivo pareado se conectou; Inicia a comunicação; É feita a; checagem da variavel de erro; Erro = 0; SIM; Envia uma menssagem informando o erro; NÃO; É enviada uma; menssagem de saudação; aguarda 2 segundos; Lê a entrada serial; Entrada != ' '; é salva; Salva o arquivo com SUDO; Desabilita a interface de rede; Codigo de retorno = 0; Habilita a interface de rede; Inicia a criação; de contas; Exibe o erro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

Envia uma
menssagem,
solicitando a
entrada do
nome da rede
WIFI

entrada da
senha da rede

Nome da rede

Entrada != ' ' Senha da rede

Gera arquivo
configuração
de rede WIFI

Verifica a
saida do
processo em
busca de erro

Envia via serial
uma
menssagem
indicando que a
configuração de
WIFI foi feita
corretamente

É solicitado o
envio de um
nome de
usuario

Endereço IP é
salvo em uma
variavel

envio de uma
senha para o

Usuario e
Senha são
salvos em um
arquivo JSON

arquivo: ChecagemDeinicializacao.log

Imprime a saida:
Configuracao
completa!
tanto no terminal
como na saida serial

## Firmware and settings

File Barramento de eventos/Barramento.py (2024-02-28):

from flask import Flask, request, Response
import requests
import socket
import json

app = Flask(__name__)

HOST = 'http://127.0.0.1'
PORTA_CAMERA = 8000
PORTA_LUZ = 9000
PORTA_MICROFONE = 7000
PORTA_Bracelete = 3000

IP_Celular = []
PORTA_Celular = []
Usuario = ''
Senha_Usuario = ''
Usuarios = {}


def ler_arquivo_json(nome_arquivo):
    try:
        with open(nome_arquivo, 'r') as arquivo:
            dados = json.load(arquivo)
        return dados
    except FileNotFoundError:
        print("Arquivo não encontrado. Será criado um novo arquivo.")
        return {}


def escrever_arquivo_json(nome_arquivo, dados):
    with open(nome_arquivo, 'w') as arquivo:
        # Escreve o log no arquivo em uma nova linha
        arquivo.write(json.dumps(dados) + '\n')
    # print("Dados salvos com sucesso!")


def adicionar_dicionario(dados, novo_dicionario):
    dados.append(novo_dicionario)
    return dados


nome_arquivo = 'Usuarios/Usuario.json'
dados = ler_arquivo_json(nome_arquivo)


def Autenticar(usuario, senha, IP):
    if IP != '127.0.0.1':
        global Usuario, Senha_Usuario, nome_arquivo
        print(usuario,senha,IP)
        usuario_OK = 0
        senha_OK = 0
        Usr = ler_arquivo_json(nome_arquivo)
        for i in Usr:
            if i['Usuario'] == usuario:
                usuario_OK = 1
        for i in Usr:
            if i['Senha'] == senha:
                senha_OK = 1
        if usuario_OK + senha_OK == 2:
            return 1
        else:
            return -1
    else:
        return 1


# Essa rota serve para inscrever o celular como Observer dos eventos do bebe, para evitar excessivo trafego na rede
@app.route('/', methods=['POST'])
def home():
    global IP_Celular
    global PORTA_Celular
    # Obtém o endereço IP do celular para Avisar quando houver mudanças de estado
    ip = request.remote_addr
    dados = json.loads(request.data.decode())
    print(dados)
    auth = Autenticar(usuario=dados['usuario'], senha=dados['senha'], IP=ip)
    if auth == 1:
        if ip not in IP_Celular:
            IP_Celular.append(ip)
            PORTA_Celular.append(dados['porta'])
            print("Endereço IP do Celular:", IP_Celular)
            print("PORTA do Celular:", PORTA_Celular)
        else:
            print('Celular ja cadastrado')
        return 'usuario autenticado'
    else:
        return 'Credenciais invalidas!'


@app.route('/evento', methods=['POST'])
def ouvir_eventos():
    try:
        global IP_Celular
        global PORTA_Celular
        # Essa rota é para uso exclusivo dos serviços
        if str(request.remote_addr) == '127.0.0.1':
            tipo = int(request.args.get('tipo'))
            if tipo == 1:  # Evento de Movimentacao
                for id, cellIP in enumerate(IP_Celular):
                    print("evento 1")
                    # Cria um objeto de soquete TCP/IP
                    sock = socket.socket(socket.AF_INET, socket.SOCK_STREAM)
                    print(f'cell IP: {cellIP}')
                    print(f'cellporta: {PORTA_Celular[id]}')
                    # Conecta o soquete ao servidor remoto em um endereço e porta específicos
                    sock.connect((cellIP, int(PORTA_Celular[id])))
                    # Envia uma mensagem ao servidor
                    message = "Evento de Movimentacao"
                    sock.sendall(message.encode())
                    sock.close()

            if tipo == 2:  # Evento do Microfone
                for id, cellIP in enumerate(IP_Celular):
                    print("evento 2")
                    # Cria um objeto de soquete TCP/IP
                    sock = socket.socket(socket.AF_INET, socket.SOCK_STREAM)
                    print(f'cell IP: {cellIP}')
                    print(f'cellporta: {PORTA_Celular[id]}')
                    # Conecta o soquete ao servidor remoto em um endereço e porta específicos
                    sock.connect((cellIP, int(PORTA_Celular[id])))
                    # Envia uma mensagem ao servidor
                    message = "Evento de Choro"
                    sock.sendall(message.encode())
                    sock.close()

            if tipo == 3:  # Evento do Microfone
                for id, cellIP in enumerate(IP_Celular):
                    print("evento 3")
                    # Cria um objeto de soquete TCP/IP
                    sock = socket.socket(socket.AF_INET, socket.SOCK_STREAM)
                    print(f'cell IP: {cellIP}')
                    print(f'cellporta: {PORTA_Celular[id]}')
                    # Conecta o soquete ao servidor remoto em um endereço e porta específicos
                    sock.connect((cellIP, int(PORTA_Celular[id])))
                    # Envia uma mensagem ao servidor
                    message = "Evento de Risada"
                    sock.sendall(message.encode())
                    sock.close()

            if tipo == 4:  # Evento do Microfone
                for id, cellIP in enumerate(IP_Celular):
                    print("evento 4")
                    # Cria um objeto de soquete TCP/IP
                    sock = socket.socket(socket.AF_INET, socket.SOCK_STREAM)
                    print(f'cell IP: {cellIP}')
                    print(f'cellporta: {PORTA_Celular[id]}')
                    # Conecta o soquete ao servidor remoto em um endereço e porta específicos
                    sock.connect((cellIP, int(PORTA_Celular[id])))
                    # Envia uma mensagem ao servidor
                    message = "Evento de Barulho"
                    sock.sendall(message.encode())
                    sock.close()
            return '200'
        else:
            return 'Voce nao tem autorizacao para acessar esse recurso!'

    except Exception as e:
        # Fecha a conexão com o servidor
        print(e)

        return '500'


@app.route('/camera', methods=['GET'])
# por razões de simplicidade de streaming o método foi alterado para GET,
# porem, o usuário e a senha sao enviados via cabeçalhos, assim podendo continuar usufruindo da criptografia HTTPS TLS
def camera():
    dados = request.headers
    auth = Autenticar(usuario=dados.get('usuario'), senha=dados.get('senha'), IP=request.remote_addr)
    if auth == 1:
        tipo = int(request.args.get('tipo'))
        if tipo == 1:
            print("Imagem requisitada")
            resposta = requests.get(f'{HOST}:{PORTA_CAMERA}/imagem', stream=False)
            return Response(resposta,
                            content_type=resposta.headers['Content-Type'])
        else:
            print("Video requisitado")
            resposta = requests.get(f'{HOST}:{PORTA_CAMERA}/video', stream=True)
            return Response(resposta.iter_content(chunk_size=1024),
                            content_type=resposta.headers['Content-Type'],
                            status=resposta.status_code)
    else:
        return 'Credenciais invalidas!'


@app.route('/microfone', methods=['POST'])
def audio():
    dados = json.loads(request.data.decode())
    auth = Autenticar(usuario=dados['usuario'], senha=dados['senha'], IP=request.remote_addr)
    if auth == 1:
        tipo = int(request.args.get('tipo'))
        if tipo == 1:
            resposta = requests.get(f'{HOST}:{PORTA_MICROFONE}/microfone')
            return resposta.json()
        if tipo == 2:
            resposta = requests.get(f'{HOST}:{PORTA_MICROFONE}/microfoneLog')
            return resposta.json()
    else:
        return 'Credenciais invalidas!'


@app.route('/iluminacao', methods=['POST'])
def iluminacao():
    dados = json.loads(request.data.decode())
    auth = Autenticar(usuario=dados['usuario'], senha=dados['senha'], IP=request.remote_addr)
    if auth == 1:
        tipo = int(request.args.get('tipo'))
        if tipo == 1:
            resposta = requests.get(f'{HOST}:{PORTA_LUZ}/Ligar')
            return resposta.json()
        if tipo == 2:
            resposta = requests.get(f'{HOST}:{PORTA_LUZ}/Desligar')
            return resposta.json()
        if tipo == 3:
            resposta = requests.get(f'{HOST}:{PORTA_LUZ}/Status')
            return resposta.json()
    else:
        return 'Credenciais invalidas!'


@app.route('/bracelete', methods=['POST'])
def bracelete():
    dados = json.loads(request.data.decode())
    auth = Autenticar(usuario=dados['usuario'], senha=dados['senha'], IP=request.remote_addr)
    if auth == 1:
        tipo = int(request.args.get('tipo'))
        if tipo == 1:
            resposta = requests.get(f'{HOST}:{PORTA_Bracelete}/Status')
            return resposta.json()
        else:
            resposta = requests.get(f'{HOST}:{PORTA_Bracelete}/Logs')
            return resposta.json()
    else:
        return 'Credenciais invalidas!'


if __name__ == '__main__':
    # app.run()
    wind = 1
    linux = 0
    if wind == 1:
        hostname = socket.gethostname()
        ip = socket.gethostbyname(hostname)
        print("Endereço IP da rede:", ip)
    if linux == 1:
        s = socket.socket(socket.AF_INET, socket.SOCK_DGRAM)
        s.connect(('8.8.8.8', 80))
        ip = s.getsockname()[0]
        s.close()
        print("Endereço IP da rede:", ip)

    app.run(host='0.0.0.0', port=5000)  # para a interface de loopback (localhost)
    app.run(host=ip, port=5000)  # para a interface de rede externa

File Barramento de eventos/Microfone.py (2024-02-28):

import numpy as np
import pyaudio
import time
import librosa
import requests
from sklearn.preprocessing import StandardScaler
import pickle
from datetime import datetime  # Importar o módulo datetime
import json

from flask import Flask, make_response, jsonify

app = Flask(__name__)

log = {}


# Função para ler o arquivo JSON
# Função para ler o arquivo JSON
def ler_arquivo_json(nome_arquivo):
    try:
        with open(nome_arquivo, 'r') as arquivo:
            dados = json.load(arquivo)
        return dados
    except FileNotFoundError:
        print("Arquivo não encontrado. Será criado um novo arquivo.")
        return {}


# Função para escrever o dicionário no arquivo JSON
def escrever_arquivo_json(nome_arquivo, dados):
    with open(nome_arquivo, 'w') as arquivo:
        # Escreve o log no arquivo em uma nova linha
        arquivo.write(json.dumps(dados) + '\n')
    print("Dados salvos com sucesso!")


# Função para adicionar um dicionário aos dados existentes
def adicionar_dicionario(dados, novo_dicionario):
    dados.append(novo_dicionario)
    return dados


# Ler o arquivo CSV e transformar em JSON
nome_arquivo = 'Logs/Logs_Choro.json'
# Lê os dados do arquivo JSON
dados = ler_arquivo_json(nome_arquivo)

# Exibe os dados atuais
# print("Dados atuais:")
# print(json.dumps(dados, indent=4))
# Inicializar o Pyaudio
p = pyaudio.PyAudio()
# Parâmetros do áudio
CHUNK = 1024  # Tamanho da memória temporária de áudio
RATE = 22050  # Taxa de amostragem (Hz)
FORMAT = pyaudio.paInt16  # Formato do áudio capturado
Durcao_Audio = 5  # Duração do clipe de áudio a ser capturado (em segundos)


##====================================================================
# Parâmetros para captura do som ambiente
DURACAO_AMOSTRAGEM = 5  # Duração da amostragem em segundos
NUM_AMOSTRAS = int(DURACAO_AMOSTRAGEM * RATE)

# Inicializar o buffer para captura do som ambiente
som_ambiente = np.array([])

# Função para capturar o som ambiente
def capturar_som_ambiente(in_data, frame_count, time_info, status):
    global som_ambiente
    som_ambiente = np.append(som_ambiente, np.frombuffer(in_data, dtype=np.int16))
    if len(som_ambiente) >= NUM_AMOSTRAS:
        return None, pyaudio.paComplete
    return None, pyaudio.paContinue

# Capturar o som ambiente
stream_som_ambiente = p.open(format=FORMAT,
                             channels=1,
                             rate=RATE,
                             input=True,
                             frames_per_buffer=CHUNK,
                             stream_callback=capturar_som_ambiente)

print("Capturando som ambiente...")
stream_som_ambiente.start_stream()

while stream_som_ambiente.is_active():
    time.sleep(0.1)  # Aguardar a captura ser concluída

stream_som_ambiente.stop_stream()
stream_som_ambiente.close()

# Calcular o valor médio do som ambiente
valor_medio_som_ambiente = np.mean(np.abs(som_ambiente))

# Definir o limite para começar a classificação com base no valor médio
Limite_Para_comecar_a_Classificar = int(2000+valor_medio_som_ambiente)
print("o limite é : ", Limite_Para_comecar_a_Classificar)
##====================================================================


# Parâmetros de detecção de barulho
#Limite_Para_comecar_a_Classificar = 2000  # Limite de intensidade de som para detecção de barulho
Intervalo = 0.1  # Intervalo entre Detecçoes

# Carregar o modelo classificador MLP previamente treinado
with open('Modelo/Novo_Modelo_MLP_NormalizadoV3.pkl', 'rb') as file:
    modelo = pickle.load(file)
with open('Modelo/scalers_Novo_Modelo_MLP_NormalizadoV3.pkl', 'rb') as file:
    scaler = pickle.load(file)

# Inicializar o buffer de áudio
audio_buffer = []
audio_buffer_2 = []
detectado = ''


# Função de callback para captura de áudio
def callback(in_data, frame_count, time_info, status):
    global audio_buffer
    global audio_buffer_2
    global dados
    global nome_arquivo
    global log
    global detectado

    audio_data = np.frombuffer(in_data, dtype=np.int16)  # Alterar o dtype para int16
    audio_buffer.append(audio_data)

    # Verificar se houve detecção de barulho
    if len(audio_buffer) > 0 and np.max(
            np.abs(audio_buffer[-1])) > Limite_Para_comecar_a_Classificar:  # Usar np.abs para valores absolutos
        # Gravar os próximos 5 segundos de áudio em uma nova memória temporária
        audio_buffer_2.extend(audio_data)
        if len(audio_buffer_2) >= Durcao_Audio * RATE:
            # Extrair as features de áudio usando a biblioteca Librosa
            features = librosa.feature.mfcc(y=np.array(audio_buffer_2).astype(np.float32), sr=RATE,
                                            n_mfcc=100)  # Converter para float32

            # Redimensionar as features para o formato esperado pelo modelo
            features = np.mean(features, axis=1)
            features = scaler.transform(features.reshape(1, -1))  # Aplicar normalização usando o scaler

            # Realizar a predição com o modelo
            predicao = modelo.predict(features)

            # Obter a hora e o minuto atual
            hora_atual = datetime.now().hour
            minuto_atual = datetime.now().minute
            # Obter a data atual
            data_atual = datetime.now()
            dia_atual = data_atual.day
            mes_atual = data_atual.month
            ano_atual = data_atual.year

            # Imprimir o resultado da predição com a hora e o minuto atual
            log.update({'predicao': predicao[0], 'hora': hora_atual, 'minuto': minuto_atual, 'dia': dia_atual,
                        'mes': mes_atual,
                        'ano': ano_atual})

            print(
                f"Foi detectado: {log['predicao']} as {log['hora']}:{log['minuto']} "
                f"do dia {log['dia']}/{log['mes']}/{log['ano']}")

            detectado = {'predicao': predicao[0], 'hora': hora_atual, 'minuto': minuto_atual, 'dia': dia_atual,
                         'mes': mes_atual,
                         'ano': ano_atual}

            if predicao[0] == 'Crying_LimpoV3': requests.post('http://127.0.0.1:5000/evento?tipo=2')
            if predicao[0] == 'Laugh_LimpoV3': requests.post('http://127.0.0.1:5000/evento?tipo=3')
            if predicao[0] == 'Noise_LimpoV3': requests.post('http://127.0.0.1:5000/evento?tipo=4')
            # Acrescentar novo dado em JSON ao arquivo
            dados = adicionar_dicionario(dados, log)
            # Escreve os dados atualizados no arquivo JSON
            escrever_arquivo_json(nome_arquivo, dados)

            # Limpar o buffer de áudio
            audio_buffer = []
            audio_buffer_2 = []
            time.sleep(5)
            detectado = ''

    return None, pyaudio.paContinue


# Iniciar a captura de áudio
stream = p.open(format=FORMAT,  # Atualizar o formato para paInt16
                channels=1,
                rate=RATE,
                input=True,
                frames_per_buffer=CHUNK,
                stream_callback=callback)
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
